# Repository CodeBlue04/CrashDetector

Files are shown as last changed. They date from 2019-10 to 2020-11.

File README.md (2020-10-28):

# CrashDetector
My first Raspberry Pi project. The ultimate goal is to bring together data from a BerryIMU accelerometer/gyro/pressure sensor 
(with some of that code base) and a GPS unit to detect vehicle collsions and/or fires, then send that data through the Iridium 
Satellite Network using a RockBLOCK 9603 and an external antenna to a Raspberry Pi server, which then sends messages to the user's 
predetermined contact list. 

### Current State:
In its current form the sensor array works and formats the message properly for transmission, the server code ("CoreMonitor.py") is functioning as intended, and the system is working correctly for collecting test data using the Test_Version. The Test_Version is intended to help determine the G and gyroscopic rotation limits of your normal riding or driving, including a data parsing script which helps visualize the data points you collect using the test code.

Beyond the code, I've also put up .stl files of the case I designed using Autodesk Fusion 360. These are a work in progess, but the version here is perfectly fine. I'm just making minor tweaks at this point. The primary goal of the case is obviously to house the hardware, but the next highest priority is to keep the case as small as is feasible to accommodate being mounted to a wider array of vehicles. Sportbikes, for instance, have notoriously small cargo compartments (if any) and present a series of challenges. Right now I'm able to fit this iteration into the glove box of my KTM 990 Adventure along with a battery pack to run the device. 

### Present Challenge:
At present, I've connected the RockBlock 9603 and am doing battle with I2C getting it set up for a full test run. That is the challenge I'm working through at the moment, but as soon as that's complete the client device and server will both be fully functional. In the past this would have been where I stopped, but I enjoy working on this project too much to stop adding features and functionality.

### Future Plans:
The next step after testing the RockBlock is going to be an Android application which will provide messenger functionality through the satellite network.

### Additional Documentation:
The documentation (glossary, diagrams, use cases, domain model, etc.) for the project is in a constant state of change, 
but here's where it's stored and updated: 
https://docs.google.com/document/d/1mS5y7tkbaYyyo5-iuApGxk0LYctw3lzjlM7L3d9vrC4/edit?usp=sharing       

I also occasionally write about it at curiositykillscolby.com.

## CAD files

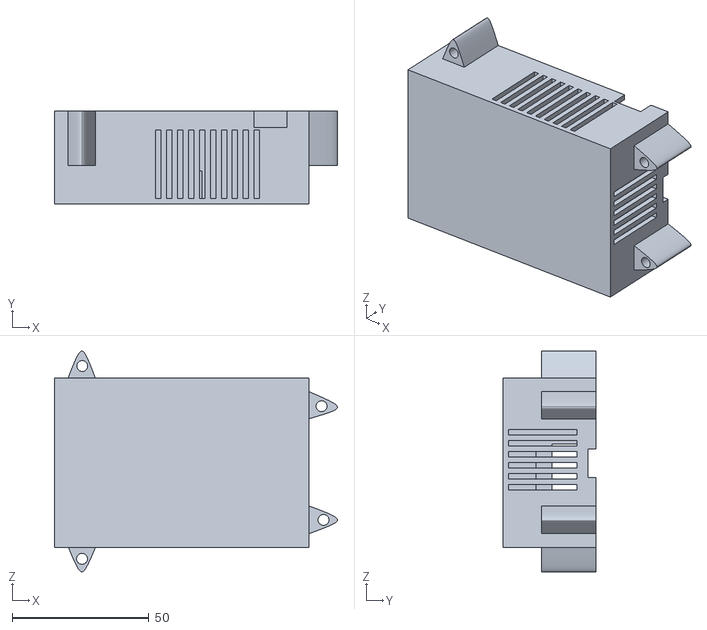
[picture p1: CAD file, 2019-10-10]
Pi Case v5.stl
103.5 x 34.0 x 80.8

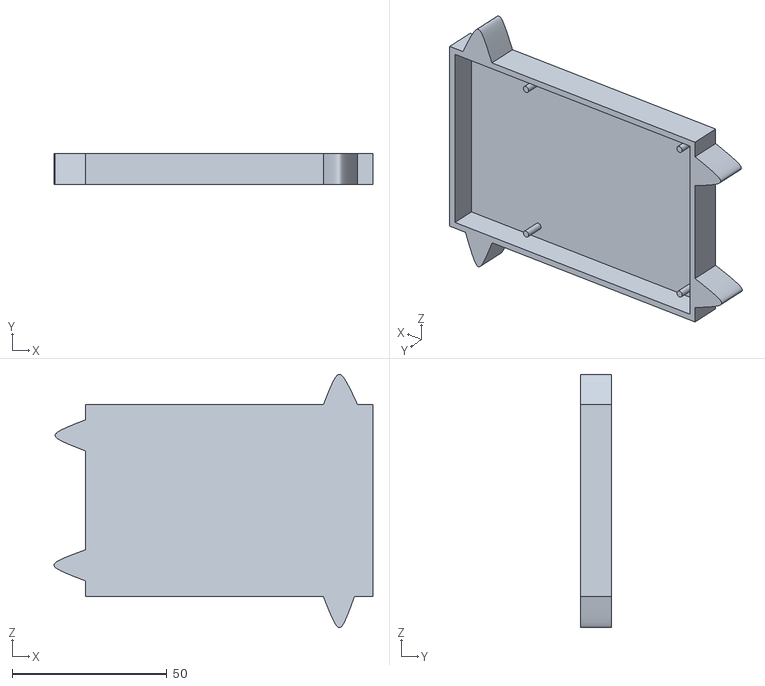
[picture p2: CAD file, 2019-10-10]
Pi Base V4 v3.stl
103.1 x 10.0 x 81.9

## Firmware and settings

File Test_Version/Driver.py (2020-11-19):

import time
import rockBlock
import logging
#import bluetooth

# -------------SatCom constants------------------
# - need port number for communicator
portID = "/dev/serial0"
# - need callback number for communicator
callback = 0

# BlueTooth socket connection
global maxXG
global maxYG
global maxZG
global maxGyroX
global maxGyroY
global maxGyroZ
global maxTemp
logging.basicConfig(filename='CrashData.log', level=logging.DEBUG)

portID = "/dev/serial0"
callback = 0

# -------- Satellite Communicator object----------
#com = rockBlock.__init__(portID, callback)

# ------function to send data from SensorArray to formatted string, then to the SatCom unit-------
def sensorEmergency(data):
    #- Message for crash with fire
    if (abs(data[0]) > 1 or abs(data[1]) > 1.5 or abs(data[2]) > 3 or abs(data[3]) > 181 or abs(data[4]) > 181 or \
        abs(data[5]) > 181) and float(data[6]) > 70:
        # - 67 characters of text. Not enough room for data. When message hits server, modify it and fill in the
        # text, regex for live testing because of 85 character message limit. Currently 89 without timestamp.
        # Probably a bool to indicate either manually generated or automatically generated messages
        output = "AutoMsg: Crash with fire! Time: " + data[9] + " gX: " + "%.1f" % data[0] + " gY: " + \
                 "%.1f" % data[1] + " gZ: " + "%.1f" % data[2] + " Lat: " + str(data[7]) + \
                 " Lon: " + str(data[8]) + " Speed: " + str(data[10])
        print(output)
        logging.info(output)
        #com.sendMessage(output)


    # - Message for a crash without fire
    elif (abs(data[0]) > 1 or abs(data[1]) > 1.5 or abs(data[2]) > 3 or abs(data[3]) > 181 or abs(data[4]) > 181 or \
        abs(data[5])) and float(data[6]) < 70:
        output = "AutoMsg: Crash! Time: " + data[9] + " gX: " + "%.1f" % data[0] + " gY: " + \
                 "%.1f" % data[1] + " gZ: " + "%.1f" % data[2] + " Lat: " + str(data[7]) + \
                 " Lon: " + str(data[8]) + " Speed: " + str(data[10]) + " Temp: " + str(data[6])
        print(output)
        logging.info(output)
        #com.sendMessage(output)
        # - Message for fire alone


    # - Message for fire
    elif float(data[6]) > 70:
        output = "AutoMsg: Fire! Time: " + +  data[9] + " Lat: " + str(data[7]) + " Lon: " + str(data[8])
        print(output)
        logging.info(output)
        #com.sendMessage(output)

    driverMonitor()

#--------------------Driver script--------------------------
def driverMonitor():
    # com = rockBlock.__init__(rockBlock(0, 0)) - uncomment when SatCom is installed

    # Python has an irritating import format
    from SensorArray import SensorArray
    sense = SensorArray()

    #- Loop that dictates the behavior of the entire controller
    while True:
        sense.sensorCaller()
        # if mes.listenForMessages(None):
        # send message through com, log in output file

        # if com.messageCheck():
        # send message to mobile device, log to output file

        time.sleep(0.03)


#- Initiates primary function loop
driverMonitor()

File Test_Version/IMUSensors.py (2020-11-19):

import datetime
import math
from ctypes import c_short
from time import sleep

from smbus import SMBus

import IMU
import SensorArray


class IMUSensors:
    # Accelerometer:
    IMU.detectIMU()  # Detect if BerryIMUv1 or BerryIMUv2 is connected.
    IMU.initIMU()  # Initialise the accelerometer, gyroscope and compass

    # Gyro
    RAD_TO_DEG = 57.29578
    M_PI = 3.14159265358979323846
    G_GAIN = 0.070  # [deg/s/LSB]  If you change the dps for gyro, you need to update this value accordingly
    AA = 0.40  # Complementary filter constant

    gyroXangle = 0.0
    gyroYangle = 0.0
    gyroZangle = 0.0

    a = datetime.datetime.now()

    # Thermometer:
    addr = 0x77
    oversampling = 3  # 0..3

    bus = SMBus(1)  # 0 for R-Pi Rev. 1, 1 for Rev. 2

    # return two bytes from data as a signed 16-bit value
    def get_short(self, data, index):
        return c_short((data[index] << 8) + data[index + 1]).value

    # return two bytes from data as an unsigned 16-bit value
    def get_ushort(self, data, index):
        return (data[index] << 8) + data[index + 1]

    # calls SensorArray class and passes array of sensor data if crash or fire detected in undateValues()
    def sensorCaller(self, dataArray):
        sense = SensorArray.SensorArray()
        sense.alertDriver(dataArray)

    #One function to rule them all. Or at least supply the bulk of sensor data.
    def updateValues(self):
        #--------------------Accelerometer sensor calculations-----------------------
        # Read the accelerometer,gyroscope and magnetometer values
        ACCx = IMU.readACCx()
        ACCy = IMU.readACCy()
        ACCz = IMU.readACCz()

        xG = (ACCx * 0.244) / 1000
        yG = (ACCy * 0.244) / 1000
        zG = (ACCz * 0.244) / 1000

        #-----------------Gyroscope sensor calculations-------------------------
        GYRx = IMU.readGYRx()
        GYRy = IMU.readGYRy()
        GYRz = IMU.readGYRz()

        ##Calculate loop Period(LP). How long between Gyro Reads
        b = datetime.datetime.now() - self.a
        self.a = datetime.datetime.now()
        LP = b.microseconds / (1000000 * 1.0)

        # Convert Gyro raw to degrees per second
        rate_gyr_x = GYRx * self.G_GAIN
        rate_gyr_y = GYRy * self.G_GAIN
        rate_gyr_z = GYRz * self.G_GAIN

        # Calculate the angles from the gyro.
        self.gyroXangle += rate_gyr_x * LP
        self.gyroYangle += rate_gyr_y * LP
        self.gyroZangle += rate_gyr_z * LP

        # Convert Accelerometer values to degrees
        self.AccXangle = (math.atan2(ACCy, ACCz) * self.RAD_TO_DEG)
        self.AccYangle = (math.atan2(ACCz, ACCx) + self.M_PI) * self.RAD_TO_DEG

        # convert the values to -180 and +180
        if self.AccYangle > 90:
            self.AccYangle -= 270.0
        else:
            self.AccYangle += 90.0

        #-------------------Thermometer calculations--------------------

        # Read whole calibration EEPROM data
        cal = self.bus.read_i2c_block_data(self.addr, 0xAA, 22)

        # Convert byte data to word values
        ac5 = self.get_ushort(cal, 8)
        ac6 = self.get_ushort(cal, 10)
        mc = self.get_short(cal, 18)
        md = self.get_short(cal, 20)

        self.bus.write_byte_data(self.addr, 0xF4, 0x2E)
        sleep(0.005)
        (msb, lsb) = self.bus.read_i2c_block_data(self.addr, 0xF6, 2)
        ut = (msb << 8) + lsb

        x1 = ((ut - ac6) * ac5) >> 15
        x2 = (mc << 11) / (x1 + md)
        b5 = x1 + x2
        t = (b5 + 8) >> 4

        temperature = t / 10.0

        #-------------------Crash condition checker-----------------------
        if temperature > 80 or abs(xG) > 4 or abs(yG) > 2.25 or abs(zG+1) > 2.5:
            print("Xg = " + str(abs(xG)) + " yG = " + str(abs(yG)) + " zG = " + str(abs(zG+1)))
            #- creates list of data to send up to the SensorArray class
            sensorData = [xG, yG, zG, self.gyroXangle, self.gyroYangle, self.gyroZangle, str(temperature)]
            #- Sends data to SensorArray
            self.sensorCaller(sensorData)

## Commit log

2019-10-25 Create Driver.py
    Test driver to narrow down the accelerometer values of your normal riding habits. Sportbikes will get different values than enduros, for example.
2019-10-25 Add files via upload
    The code for the gyro still needs work, but before that happens I have to throw nylon bolts onto the case instead of the metal ones, as they're influencing the magnets inside of the IMU board. They s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
    Once the gyro is set up I'll start testing on the RockBlock 9603.
2019-10-28 Update Driver.py
    Issues with test driver getting index out of bounds for "Speed" index. Commented, but not amended yet.
    [Driver.py]
2019-11-14 Updated Data Parser script to add counters for G readings. The counters should be used to refine event parameters in the IMUSensor class in Test_Version.
2020-01-28 Beginning testing on SatCom. Added logging in the driver for comparison with logs in the SatCom library pyRockBlock.
2020-10-28 Cleaning up code before diving back into serial input issues.
    [Driver.py, GPS.py, IMUSensors.py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]
2020-11-19 Testing uart cable
2020-11-19 Cleaned up code, updated portID, removed test print statement from GPS, added test print statement to Test_Version/IMUSensor
2020-11-19 Added rockBlock to Test_version, updated crash conditions for Test_Version/Driver.py
    [IMUSensors.py, rockBlock.py]
2020-11-19 Drivers made to loop back to monitor in case of multiple collisions or later fire
    [Driver.py]
